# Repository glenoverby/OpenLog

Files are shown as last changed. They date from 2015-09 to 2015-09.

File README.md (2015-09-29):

OpenLog
=======

This is a fork of the SparkFun OpenLog project.  It records data from the
analog inputs instead of the serial port.

Analog was meant to be an option, but right now it's the only option.

The pcb is a "version 1.0" and needs some changes made:
 - go back to the voltage regulator that SFE used
   (this pinout is for a TPS77033 which oscillates with a ceramic output cap)
 - get a microSD socket that can be hand soldered
 - put some screw holes on it!
 - run +3.3v to the off-board header
 - 0603 might be great in production, but 0805 is a lot nicer for hand soldering

[OpenLog  
*OpenLog (DEV-09530)*](https://www.sparkfun.com/products/9530)

OpenLog is an open source data logger that works over a simple serial connection and supports microSD cards up to 64GB. 

License Information
-------------------

The hardware design and firmware are released under [Creative Commons Share-alike 3.0](http://creativecommons.org/licenses/by-sa/3.0/).  
The FAT16/FAT32 firmware was originally designed by Roland Riegel and is released under [GPL v2](http://www.gnu.org/licenses/gpl-2.0.html).  
OpenLog v2.0 and above uses sdfatlib written by Bill Greiman and is released under [GPL v3](http://www.gnu.org/licenses/gpl-3.0.html).  
The OpenLog firmware was created by SparkFun Electronics, and is open source so please feel free to do anything you want with it; 
you buy me a beer if you use this and we meet someday ([Beerware license](http://en.wikipedia.org/wiki/Beerware)).

Repository Contents
-------------------
* **/Firmware** 
    * OpenLog_v3 - Firmware that ships with OpenLog
    * OpenLog_v3_Light - Alternative version to allow for larger buffers
    * Examples - Example Arduino code for controlling and testing OpenLog
* **/Fritzing** - Fritzing image showing the connections between the OpenLog and an FTDI Basic
* **/Hardware** - Hardware design files for the OpenLog PCB. These files were designed in Eagle CAD.

Version History
---------------

OpenLog v1 is stable but only supports FAT16 and up to 2GB.  

OpenLog v2 is a bit buggy but supports FAT32 and SD cards up to 16GB.  

OpenLog v3 is stable, supports FAT32 cards up to 64GB and supports higher record speeds (115200/57600).

* **v1.0**  Buggy initial release
* **v1.1**  Small changes to system settings and EEPROM storage.
* **v1.2**  Added wild card to listing and remove commands. Added read file command.
* **v1.3**  Added auto buffer record if unit sits idle for more than 5 seconds.
* **v1.4**  Increase buffer size to 900 bytes. Pinning down URU errors.
* **v1.5**  Lowered power consumption to ~2mA avg. Added 4800 and 19200 baud rates.
* **v1.51** Added configurable escape character, and escape character amount.
* **v1.6**  Added ability to configure via config.txt file.
* **v2.0**  Massive overhaul. Ported to sdfatlib. Now supports FAT16/FAT32/SD/SDHC.
* **v2.1**  Power save not working. Fixed issue 35. Dropping characters at 57600bps.
* **v2.11** Tested with 16GB microSD. Fixed issues 30 & 34. Re-enable power save.
* **v2.2**  Modified append_file() to use a single buffer. Increased HardwareSerial.cpp buffer to 512 bytes.
* **v2.21** ringp fork brought in. rm dir, cd .., and wildcards now work!
* **v2.3**  Migrated to v10.10.10 of sdfatlib. Moved to inline RX interrupt and buffer.
* **v2.4**  Merged ringp updates. Commands cd, rm, ls work again!
* **v2.41** Power loss bug fixed. Adding support for 38400bps for testing with SparkFum 9DOF IMU logging. 
* **v2.5**  Added software reset command. Modified the read command to print extended ASCII characters.
* **v2.51** Changed command prompt control to ignore \n for easier control from microcontroller.
* **v3.0**  Migration to Arduino v1.0 and better recording speed at 115200bps and 57600bps.
* **v3.1**  Better handling of recording during power loss.
* **v3.2**  Freed up RAM for larger RX ring buffer. Added support for wildcards and ability to ignore emergency override.
* **v3.3**  Added ability to ignore escape character checking and corrected incremental log naming.

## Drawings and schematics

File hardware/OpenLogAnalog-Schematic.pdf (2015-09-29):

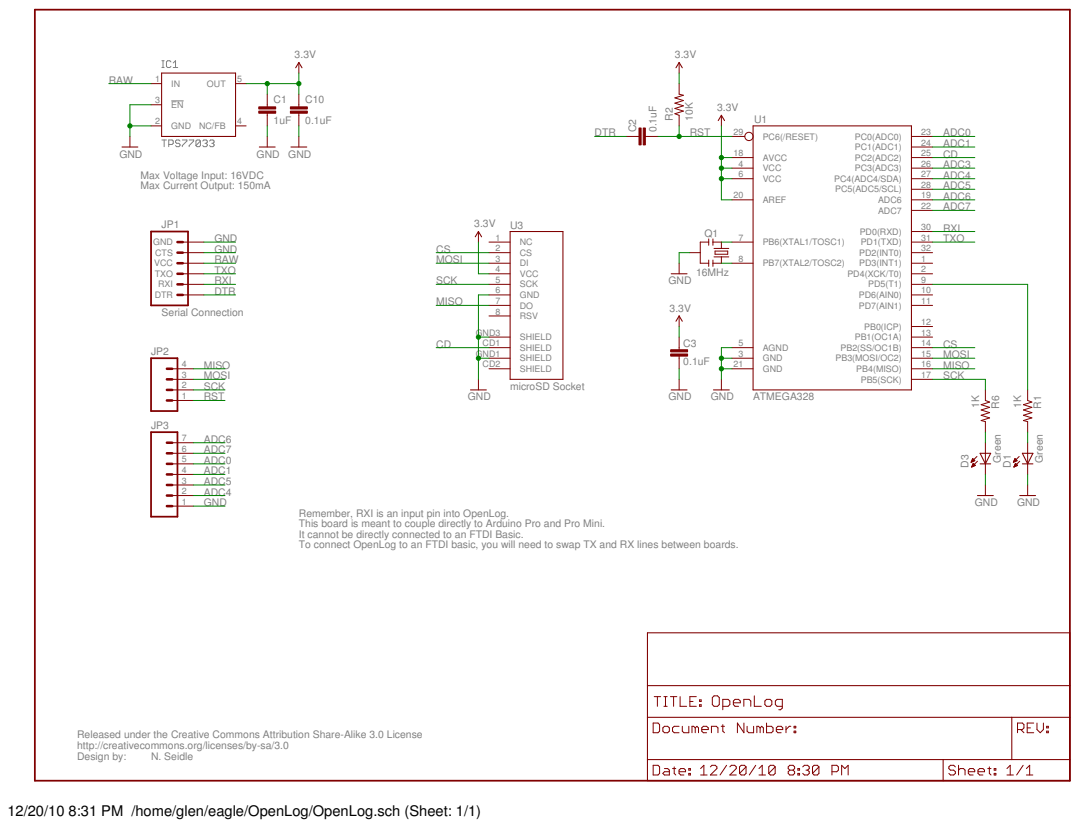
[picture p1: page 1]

Remember, RXI is an input pin into OpenLog. This board is meant to couple directly to Arduino Pro and Pro Mini.
It cannot be directly connected to an FTDI Basic. To connect OpenLog to an FTDI basic, you will need to swap TX and RX lines between boards.

Released under the Creative Commons Attribution Share-Alike 3.0 License
http://creativecommons.org/licenses/by-sa/3.0
Design by:

12/20/10 8:31 PM /home/glen/eagle/OpenLog/OpenLog.sch (Sheet: 1/1)

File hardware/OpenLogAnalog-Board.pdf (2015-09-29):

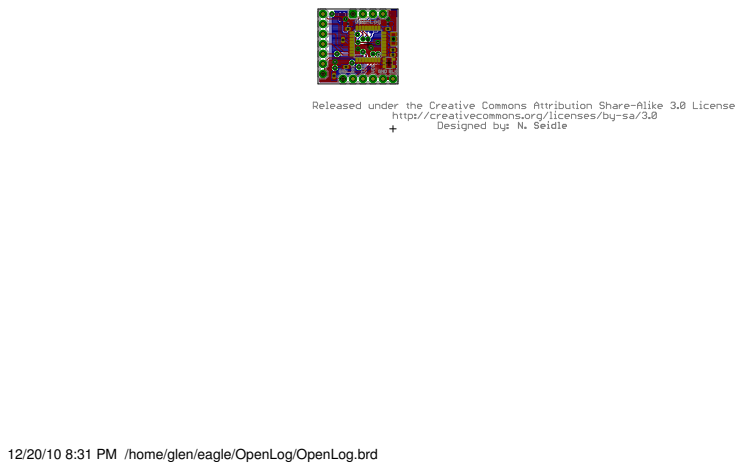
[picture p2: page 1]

12/20/10 8:31 PM /home/glen/eagle/OpenLog/OpenLog.brd

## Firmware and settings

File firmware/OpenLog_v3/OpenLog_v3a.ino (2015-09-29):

 /*
 12-3-09
 Nathan Seidle
 SparkFun Electronics 2012
 
 OpenLog hardware and firmware are released under the Creative Commons Share Alike v3.0 license.
 http://creativecommons.org/licenses/by-sa/3.0/
 Feel free to use, distribute, and sell varients of OpenLog. All we ask is that you include attribution of 'Based on OpenLog by SparkFun'.
 
 OpenLog is based on the work of Bill Greiman and sdfatlib: http://code.google.com/p/sdfatlib/
 
 OpenLog is a simple serial logger based on the ATmega328 running at 16MHz. The ATmega328
 is able to talk to high capacity (larger than 2GB) SD cards. The whole purpose of this
 logger was to create a logger that just powered up and worked. OpenLog ships with an Arduino/Optiboot 
 115200bps serial bootloader running at 16MHz so you can load new firmware with a simple serial
 connection.
 
 OpenLog automatically works with 512MB, 1GB, 2GB, 4GB, 8GB, and 16GB microSD cards. We recommend FAT16 for 2GB and smaller cards. We
 recommend FAT32 for 4GB and larger cards.
 	
 OpenLog runs at 9600bps by default. This is configurable to 1200, 2400, 4800, 9600, 19200, 38400, 57600, and 115200bps. You can alter 
 all settings including baud rate and escape characters by editing config.txt found on OpenLog.
 
 Type '?' to get a list of supported commands.
 	
 During power up, you will see '12<'. '1' indicates the serial connection is established. '2' indicates
 the SD card has been successfully initialized. '<' indicates OpenLog is ready to receive serial characters.
 
 Recording constant 115200bps datastreams are supported. Throw it everything you've got! To acheive this maximum record rate, please use the
 SD card formatter from : http://www.sdcard.org/consumers/formatter/. The fewer files on the card, the faster OpenLog is able to begin logging.
 200 files is ok. 2GB worth of music and pictures is not.
 	
 To a lower dir, use 'cd ..' instead of 'cd..'.
 	
 Only standard 8.3 file names are supported. "12345678.123" is acceptable. "123456789.123" is not.
 
 All file names are pushed to upper case. "NewLog.txt" will become "NEWLOG.TXT".
 
 Type 'set' to enter baud rate configuration menu. Select the baud rate and press enter. You will then 
 see a message 'Going to 9600bps...' or some such message. You will need to power down OpenLog, change 
 your system UART settings to match the new OpenLog baud rate and then power OpenLog back up.
 
 If you get OpenLog stuck into an unknown baudrate, there is a safety mechanism built-in. Tie the RX pin 
 to ground and power up OpenLog. You should see the LEDs blink back and forth for 2 seconds, then blink 
 in unison. Now power down OpenLog and remove the RX/GND jumper. OpenLog is now reset to 9600bps.
 	
 Please note: The preloaded Optiboot serial bootloader is 0.5k, and begins at 0x7E00 (32,256). If the code is
 larger than 32,256 bytes, you will get verification errors during serial bootloading.
 
 STAT1 LED is sitting on PD5 (Arduino D5) - toggles when character is received
 STAT2 LED is sitting on PB5 (Arduino D13) - toggles when SPI writes happen
 
 LED Flashing errors @ 2Hz:
 No SD card - 3 blinks
 Baud rate change (requires power cycle) - 4 blinks
 
 OpenLog regularly shuts down to conserve power. If after 0.5 seconds no characters are received, OpenLog will record any unsaved characters
 and go to sleep. OpenLog will automatically wake up and continue logging the instant a new character is received.
 
 1.55mA idle
 15mA actively writing
 
 Input voltage on VCC can be 3.3 to 12V. Input voltage on RX-I pin must not exceed 6V. Output voltage on
 TX-O pin will not be greater than 3.3V. This may cause problems with some systems - for example if your
 attached microcontroller requires 4V minimum for serial communication (this is rare).
 
 OpenLog has progressed significantly over the past three years. Please see Changes.txt or GitHub for a full change log.
 
 
 v3.0 Re-write of core functions. Support under Arduino v1.0. Now supports full speed 57600 and 115200bps! Lower standby power.
 
 28354 bytes out of 32256.
 
 Be sure to check out https://github.com/nseidle/OpenLog/issues for issues that have been resolved up to this version.
 
 Update to new beta version of SerialPort lib from Bill Greiman. Update to Arduino v1.0. With Bill's library, we don't need to hack the HardwareSerial.cpp.
 Re-wrote the append function. This function is the most important function and has the most affect on record accuracy. We are 
 now able to record at 57600 and 115200bps at full blast! The performance is vastly improved.
 
 To compile v3.0 you will need Arduino v1.0 and Bill's beta library: http://beta-lib.googlecode.com/files/SerialLoggerBeta20120108.zip
 Unzip 'SerialPortBeta20120106.zip' and 'SdFatBeta20120108.zip' to the libraries directory and close and restart Arduino.
 
 Small stuff:
 Redirected all static strings to point to the new way in Arduino 1.0: NewSerial.print(F("asdf")); instead of PgmPrint
 Figured out lower standby power from the low-power tutorial: http://www.sparkfun.com/tutorials/309
 Corrected #define TRUE to built-in supported 'true'
 Re-arranged some functions
 Migrating to Uno bootloader to get an additional 1500 bytes of program space
 Replumbed everything to get away from hardware UART
 Reduced # of sub directory support from 15 levels to 2 to allow for more RAM
 
 Wildcard remove is supported in v3.1
 Wildcard is supported in v3.2
 efcount and efinfo is not yet supported in v3.0
 
 Testing at 115200. First test with clean/empty card. The second test is with 193MB across 172 files on the microSD card.
 1GB: 333075/333075, 333075/333075
 8GB: 333075/333075, 333075/333075
 16GB: 333075/333075, 333075/333075
 The card with tons of files may have problems. Whenever possible, use a clean, empty, freshly formatted card.
 
 Testing at 57600. First test with clean/empty card. The second test is with 193MB across 172 files on the microSD card.
 1GB: 111075/111075, 111075/111075
 8GB: 111075/111075, 111075/111075
 16GB: 111075/111075, 111075/111075
 The card with tons of files may have problems. Whenever possible, use a clean, empty, freshly formatted card.
 
 
 v3.1 Fixed bug where entire log data is lost when power is lost.
 
 Added fix from issue 76: https://github.com/nseidle/OpenLog/issues/76
 Added support for verbose and echo settings recorded to the config file and EEPROM.
 Bugs 101 and 102 fixed with the help of pwjansen and wilafau - thank you!!
 
 Because of the new code to the cycle sensitive append_log loop, 115200bps is not as rock solid as I'd like.
 I plan to correct this in the Light version.
 
 Added a maxLoop variable calculation to figure out how many bytes to receive before we do a forced file.sync.
 
 
 v3.11 Added freeMemory support for RAM testing.
 
 This was taken from: http://arduino.cc/playground/Code/AvailableMemory
 
 
 v3.12 Using freeMemory() function from JeeLabs. Seems to be working well.
 
 Echo on/off is working again with a reduction of the buffer from 600 to 500.
 Code size is up a bit to 29,282. We have free RAM of about 527 after "2" and 444 once we've begun append_file.
 
 
 v3.13 Changed the string compares from strings in RAM (strcmp) to strings located in flash memory (strcmp_P).
 
 We used to use this type of compare: else if(strcmp_P(command_arg, PSTR("md")) == 0)
 I'm not sure how or why I got away from it, but bringing it back frees up a lot of RAM. I bet I got rid of PSTRs
 in an attempt to reduce code size when I should have been more worried about RAM running out.
 RAM is currently at 645 after 2 and 562 once we've begun append_file. 
 Also figured out there is sprintf_P built just for PSTRs. Neat!
 RAM is currently at 779 after 2 and 696 once we've begun append_file.
 Removal of strncmp(). I believe we used it to reduce flash footprint. Once migrated to PSTR, it makes it worse.
 
 29172 bytes
 
 v3.14 Added support for 1200bps Issue 139
 
 29354 bytes
 
 v3.20 Re-wrote baud rate system to support anything from 300bps to 1,000,000bps
 
 28,640 bytes (yay! saved a bunch by removing the text-based menu system)
 
 Added support for newlines when using the 'write' command.
 Should fix issue #149.
 
 Fixed issue #134: When removing files and there is a directory, all wildcard files are now removed correctly.
 Fixed issue #135: ls with wildcard works again. Thank you dlkeng!
 
 v3.3
 
 28,350 Using the latest SdFat lib from Bill: https://code.google.com/p/sdfatlib/downloads/list
 Using Arduino v1.5.4
 
 Fixed issue 160: https://github.com/sparkfun/OpenLog/issues/160
 Logs now increment continously regardless of what file may be on the card. Adds 6 bytes.
 
 Added feature/issue 166: If escape characters is set to zero, it ignores all escape characters. Adds 200 bytes.
 
 Fixed issue 164 - Reducing RX buffer size to allow for correct baud rate changes.
 SerialPort<0, 780, 0> NewSerial; //Fails
 SerialPort<0, 750, 0> NewSerial; //Works
 
 Fixed issue 163 - using dlkeng's fix to get baud rate to work at 300 baud. 
 Adds 80 bytes
 
 Increased escape character limits to 0 and 254. If set to zero, it will not check for escape characters.
 
 */

#include <SdFat.h> //We do not use the built-in SD.h file because it calls Serial.print
#include <SerialPort.h> //This is a new/beta library written by Bill Greiman. You rock Bill!
#include <EEPROM.h>

SerialPort<0, 700, 0> NewSerial;
//SerialPort<0, 750, 0> NewSerial;
//SerialPort<0, 680, 0> NewSerial;
//SerialPort<0, 580, 0> NewSerial;
//This is a very important buffer declaration. This sets the <port #, rx size, tx size>. We set
//the TX buffer to zero because we will be spending most of our time needing to buffer the incoming (RX) characters.
//900 works on minimal implementation, doesn't work with the full command prompt
//850 fails on echo on/off
//800 works with full command shell
//700 works very well at 115200
//600 works well at 115200

#include <avr/sleep.h> //Needed for sleep_mode
#include <avr/power.h> //Needed for powering down perihperals such as the ADC/TWI and Timers
//#include <avr/wdt.h> //Needed for the reset command - uses watch dog timer to reset IC

//Debug turns on (1) or off (0) a bunch of verbose debug statements. Normally use (0)
//#define DEBUG  1
#define DEBUG  0

//The bigger the receive buffer, the less likely we are to drop characters at high speed. However, the ATmega has a limited amount of
//RAM. This debug mode allows us to view available RAM at various stages of the program
//#define RAM_TESTING  1 //On
#define RAM_TESTING  0 //Off

//#define Reset_AVR() wdt_enable(WDTO_1S); while(1) {} //Correct way of resetting the ATmega, but doesn't work with 
//Arduino pre-Optiboot bootloader
void(* Reset_AVR) (void) = 0; //Dirty way of resetting the ATmega, but it works for now

// The folder track depth is used by "cd .." and "pwd"
// This looks like an ugly hack but the sdfatlib is not supporting going back to previous folder yet.
// The current handling of "cd .." should be removed when it's available in the sdfat library.
//#define FOLDER_TRACK_DEPTH 15
#define FOLDER_TRACK_DEPTH 2 //Decreased for more RAM access
char folderTree[FOLDER_TRACK_DEPTH][12];

#define CFG_FILENAME "config.txt" //This is the name of the file that contains the unit settings

#define MAX_CFG "115200,103,214,0,1,1,0\0" //= 115200 bps, escape char of ASCII(103), 214 times, new log mode, verbose on, echo on, ignore RX false. 
#define CFG_LENGTH (strlen(MAX_CFG) + 1) //Length of text found in config file. strlen ignores \0 so we have to add it back 
#define SEQ_FILENAME "SEQLOG00.TXT" //This is the name for the file when you're in sequential mode

//Internal EEPROM locations for the user settings
#define LOCATION_SYSTEM_SETTING		0x02
#define LOCATION_FILE_NUMBER_LSB	0x03
#define LOCATION_FILE_NUMBER_MSB	0x04
#define LOCATION_ESCAPE_CHAR		0x05
#define LOCATION_MAX_ESCAPE_CHAR	0x06
#define LOCATION_VERBOSE                0x07
#define LOCATION_ECHO                   0x08
#define LOCATION_BAUD_SETTING_HIGH	0x09
#define LOCATION_BAUD_SETTING_MID	0x0A
#define LOCATION_BAUD_SETTING_LOW	0x0B
#define LOCATION_IGNORE_RX		0x0C

#define BAUD_MIN  300
#define BAUD_MAX  1000000

#define MODE_NEWLOG	0
#define MODE_SEQLOG     1
#define MODE_COMMAND    2

//STAT1 is a general LED and indicates serial traffic
#define STAT1  5 //On PORTD
#define STAT1_PORT  PORTD
#define STAT2  5 //On PORTB
#define STAT2_PORT  PORTB
const byte statled1 = 5;  //This is the normal status LED
const byte statled2 = 13; //This is the SPI LED, indicating SD traffic

//Blinking LED error codes
#define ERROR_SD_INIT	  3
#define ERROR_NEW_BAUD	  5
#define ERROR_CARD_INIT   6
#define ERROR_VOLUME_INIT 7
#define ERROR_ROOT_INIT   8
#define ERROR_FILE_OPEN   9

#if !DEBUG
// Using OpenLog in an embedded environment only if not in debug mode. The reason for this
// is that we are out of space if the simple embedded is included
#define INCLUDE_SIMPLE_EMBEDDED
#endif

//These are bit locations used when testing for simple embedded commands.
#define ECHO			0x01
#define EXTENDED_INFO		0x02
#define OFF  0x00
#define ON   0x01

#ifdef INCLUDE_SIMPLE_EMBEDDED
#define EMBEDDED_END_MARKER	0x08
#endif

Sd2Card card;
SdVolume volume;
SdFile currentDirectory;

long setting_uart_speed; //This is the baud rate that the system runs at, default is 9600. Can be 1,200 to 1,000,000
byte setting_system_mode; //This is the mode the system runs in, default is MODE_NEWLOG
byte setting_escape_character; //This is the ASCII character we look for to break logging, default is ctrl+z
byte setting_max_escape_character; //Number of escape chars before break logging, default is 3
byte setting_verbose; //This controls the whether we get extended or simple responses.
byte setting_echo; //This turns on/off echoing at the command prompt
byte setting_ignore_RX; //This flag, when set to 1 will make OpenLog ignore the state of the RX pin when powering up

//The number of command line arguments
//Increase to support more arguments but be aware of the memory restrictions
//command <arg1> <arg2> <arg3> <arg4> <arg5>
#define MAX_COUNT_COMMAND_LINE_ARGS 5
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
void loop(void)
{
  //If we are in new log mode, find a new file name to write to
  if(setting_system_mode == MODE_NEWLOG)
    append_file(newlog()); //Append the file name that newlog() returns

  //If we are in sequential log mode, determine if seqlog.txt has been created or not, and then open it for logging
  if(setting_system_mode == MODE_SEQLOG)
    seqlog();

  //Once either one of these modes exits, go to normal command mode, which is called by returning to main()
  command_shell();

  while(1); //We should never get this far
}

//Log to a new file everytime the system boots
//Checks the spots in EEPROM for the next available LOG# file name
//Updates EEPROM and then appends to the new log file.
//Limited to 65535 files but this should not always be the case.
char new_file_name[13];

char* newlog(void)
{
  byte msb, lsb;
  uint16_t new_file_number;

  SdFile newFile; //This will contain the file for SD writing

  //Combine two 8-bit EEPROM spots into one 16-bit number
  lsb = EEPROM.read(LOCATION_FILE_NUMBER_LSB);
  msb = EEPROM.read(LOCATION_FILE_NUMBER_MSB);

  new_file_number = msb;
  new_file_number = new_file_number << 8;
  new_file_number |= lsb;

  //If both EEPROM spots are 255 (0xFF), that means they are un-initialized (first time OpenLog has been turned on)
  //Let's init them both to 0
  if((lsb == 255) && (msb == 255))
  {
    new_file_number = 0; //By default, unit will start at file number zero
    EEPROM.write(LOCATION_FILE_NUMBER_LSB, 0x00);
    EEPROM.write(LOCATION_FILE_NUMBER_MSB, 0x00);
  }

  //The above code looks like it will forever loop if we ever create 65535 logs
  //Let's quit if we ever get to 65534
  //65534 logs is quite possible if you have a system with lots of power on/off cycles
  if(new_file_number == 65534)
  {
    //Gracefully drop out to command prompt with some error
    NewSerial.print(F("!Too many logs:1!"));
    return(0); //Bail!
  }

  //If we made it this far, everything looks good - let's start testing to see if our file number is the next available

  //Search for next available log spot
  //char new_file_name[] = "LOG00000.TXT";
  //char new_file_name[13];
  while(1)
  {
    sprintf_P(new_file_name, PSTR("LOG%05d.TXT"), new_file_number); //Splice the new file number into this file name

    //Try to open file, if fail (file doesn't exist), then break
    if (newFile.open(&currentDirectory, new_file_name, O_CREAT | O_EXCL | O_WRITE)) break;

    //Try to open file and see if it is empty. If so, use it.
    if (newFile.open(&currentDirectory, new_file_name, O_READ)) 
    {
      if (newFile.fileSize() == 0)
      {
        newFile.close();        // Close this existing file we just opened.
        return(new_file_name);  // Use existing empty file.
      }
      newFile.close(); // Close this existing file we just opened.
    }

    //Try the next number
    new_file_number++;
    if(new_file_number > 65533) //There is a max of 65534 logs
    {
      NewSerial.print(F("!Too many logs:2!"));
      return(0); //Bail!
    }
  }
  newFile.close(); //Close this new file we just opened

  new_file_number++; //Increment so the next power up uses the next file #

  //Record new_file number to EEPROM
  lsb = (byte)(new_file_number & 0x00FF);
  msb = (byte)((new_file_number & 0xFF00) >> 8);

  EEPROM.write(LOCATION_FILE_NUMBER_LSB, lsb); // LSB

  if (EEPROM.read(LOCATION_FILE_NUMBER_MSB) != msb)
    EEPROM.write(LOCATION_FILE_NUMBER_MSB, msb); // MSB

#if DEBUG
  NewSerial.print(F("\nCreated new file: "));
  NewSerial.println(new_file_name);
#endif

  return(new_file_name);
}

//Log to the same file every time the system boots, sequentially
//Checks to see if the file SEQLOG.txt is available
//If not, create it
//If yes, append to it
//Return 0 on error
//Return anything else on sucess
void seqlog(void)
{
  SdFile seqFile;

  char sequentialFileName[strlen(SEQ_FILENAME)]; //Limited to 8.3
  strcpy_P(sequentialFileName, PSTR(SEQ_FILENAME)); //This is the name of the config file. 'config.sys' is probably a bad idea.

  //Try to create sequential file
  if (!seqFile.open(&currentDirectory, sequentialFileName, O_CREAT | O_WRITE))
  {
    NewSerial.print(F("Error creating SEQLOG\n"));
    return;
  }

  seqFile.close(); //Close this new file we just opened

  append_file(sequentialFileName); 
}

//This is the most important function of the device. These loops have been tweaked as much as possible.
//Modifying this loop may negatively affect how well the device can record at high baud rates.
//Appends a stream of serial data to a given file
//Assumes the currentDirectory variable has been set before entering the routine
//Does not exit until Ctrl+z (ASCII 26) is received
//Returns 0 on error
//Returns 1 on success
byte append_file(char* file_name)
{
  SdFile workingFile;
  NewSerial.println(file_name);
  
  // O_CREAT - create the file if it does not exist
  // O_APPEND - seek to the end of the file prior to each write
  // O_WRITE - open for write
  if (!workingFile.open(&currentDirectory, file_name, O_CREAT | O_APPEND | O_WRITE)) systemError(ERROR_FILE_OPEN);
  if (workingFile.fileSize() == 0) {
    //This is a trick to make sure first cluster is allocated - found in Bill's example/beta code
    //workingFile.write((byte)0); //Leaves a NUL at the beginning of a file
    workingFile.rewind();
    workingFile.sync();
  }  

  NewSerial.print(F("<")); //give a different prompt to indicate no echoing
  digitalWrite(statled1, HIGH); //Turn on indicator LED

  const byte LOCAL_BUFF_SIZE = 128; //This is the 2nd buffer. It pulls from the larger NewSerial buffer as quickly as possible.
  byte localBuffer[LOCAL_BUFF_SIZE];
  byte checkedSpot;
  byte escape_chars_received = 0;

  const uint16_t MAX_IDLE_TIME_MSEC = 500; //The number of milliseconds before unit goes to sleep
  const uint16_t MAX_TIME_BEFORE_SYNC_MSEC = 5000;
  uint32_t lastSyncTime = millis(); //Keeps track of the last time the file was synced

  printRam(); //Print the available RAM

  //Check if we should ignore escape characters
  //If we are ignoring escape characters the recording loop is infinite and can be made shorter (less checking)
  //This should allow for recording at higher incoming rates
  if(setting_max_escape_character == 0)
  {
    //Start recording incoming characters
    //With no escape characters, do this infinitely
    while(1) {

      byte n = NewSerial.read(localBuffer, sizeof(localBuffer)); //Read characters from global buffer into the local buffer
      if (n > 0) //If we have characters, check for escape characters
      {
        workingFile.write(localBuffer, n); //Record the buffer to the card

        STAT1_PORT ^= (1<<STAT1); //Toggle the STAT1 LED each time we record the buffer

        if((millis() - lastSyncTime) > MAX_TIME_BEFORE_SYNC_MSEC) //This will force a sync approximately every 5 seconds
        { 
          //This is here to make sure a log is recorded in the instance
          //where the user is throwing non-stop data at the unit from power on to forever
          workingFile.sync(); //Sync the card
          lastSyncTime = millis();
        }

      }
      //No characters recevied?
      else if( (millis() - lastSyncTime) > MAX_IDLE_TIME_MSEC) { //If we haven't received any characters in 2s, goto sleep
        workingFile.sync(); //Sync the card before we go to sleep

        STAT1_PORT &= ~(1<<STAT1); //Turn off stat LED to save power

        //power_timer0_disable(); //Shut down peripherals we don't need
        power_spi_disable();
        sleep_mode(); //Stop everything and go to sleep. Wake up if serial character received

        power_spi_enable(); //After wake up, power up peripherals
        power_timer0_enable();

        escape_chars_received = 0; // Clear the esc flag as it has timed out
        lastSyncTime = millis(); //Reset the last sync time to now
      }

    }

  }
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
